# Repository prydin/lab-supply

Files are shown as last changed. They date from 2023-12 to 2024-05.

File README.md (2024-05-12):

# Linear 0-30V, 2A lab power supply

3d rendering

## Disclaimer

This supply has been built and tested and does work. However, I am a hobbyist doing this to learn. You are
welcome to follow along, but keep the experimental status in mind and always exercise caution when dealing
with electricity!

## Abstract

This project aims to design a high-performance, high-stability microcontroller-based lab power supply. I am
mostly doing this to learn, but also because I'm tired of cheap switchmode power supplies delivering power
riddled with RF noise.

## Principle of operation

### High voltage section

The high voltage section is very simple and consists of a regular AC inlet with a safety capacitor across it.
There is a 3A fuse in series with the hot lead and a two pole mains switch. The transformer is a 24V/4A unit
with a 12V center tap. Once rectified, the voltage reaches about 36V at my location. Mains ground is connected
to the chassis as well as the ground output terminal.

### Analog secion

32-36V AC enters the circuit at the `AC1` and `AC2` terminals and gets rectified and smoothed into approximately
36-40V DC. This voltage is then pre-regulated down to 32V through `Q3` which is gets its voltage reference the
backwards bias of `D3`. This voltage is used to power the opamps. The `CNT` input is the transformer center tap,
which should be around 15V and is used to create the +12V and +5V voltages.

The `U1D` opamp acts as a voltage regulation amplifier and expects a control voltage between 0-4.096V on its postive input. The feedback loop is tuned
to 7.32x amplification, resulting in an output voltage ranging from 0-30V. The Darlington pair at `Q3` acts
as a emitter follower current amplifier.

Current regulation is based on a high-side current sensing resistor, `R27`. The differential voltage across the
current sense resistor is amplified to a 0-2.5V signal using an INA225 current sense amplifier. This voltage is
then sent to the positivie input of `U1A`. The control circuitry feeds a 0-4.096V signal
to the `V_ISET` input, which is scaled down to 0-2.5V through a resistor network. This voltage is then fed to the
negative input of `U1A`. When the voltage from the current sense amplifier goes above the control voltage on the negative input,
the opamp will source current to Q2, which brings the base on Q3 low until the current is limited to the
set value. `Q3` is needed since we want to keep R24 relatively low to avoid voltage drop at high output currents,
while making sure `U1A` isn't sourcing or sinking too much current. `Q1` acts as a simple switch for turning on
the current limit indicator LED.

### Digital section

The digital section is based on a Adafruit ItsyBitsy 5V, which is essentially an Atmel ATMega 32u4 with some
support circuitry. This was chosen to simplify the design and keep everything as through hole. The digital
section is responsible for feeding the `V_VSET` and `V_ISET` voltages to the the analog section, as well
as measuring and presenting actual voltages and currents.

A key component is the LMZ4040DBZ voltage reference, which provides a stable 4.096V reference used by the
rest of the circuit.

The control voltages are generated by an MPC4922 12-bit DAC and fed directly to the analog section. The user
sets the desired voltage and current using two rotary encoders which can be pushed to switch between a "fine"
and "coarse" mode.

The output voltage of the supply is measured by an MCP3202 ADC through a voltage divider network to bring the
voltage down to 0-4.096V. Further overvoltage protection is offered by the `D12` clamping diode. Current is
measured in a similar way, but since that signal is in the 0-1V range, it is first amplified 4.096x by `U1B`.
This signal is also clamped to the 4.096V reference through `D10`.

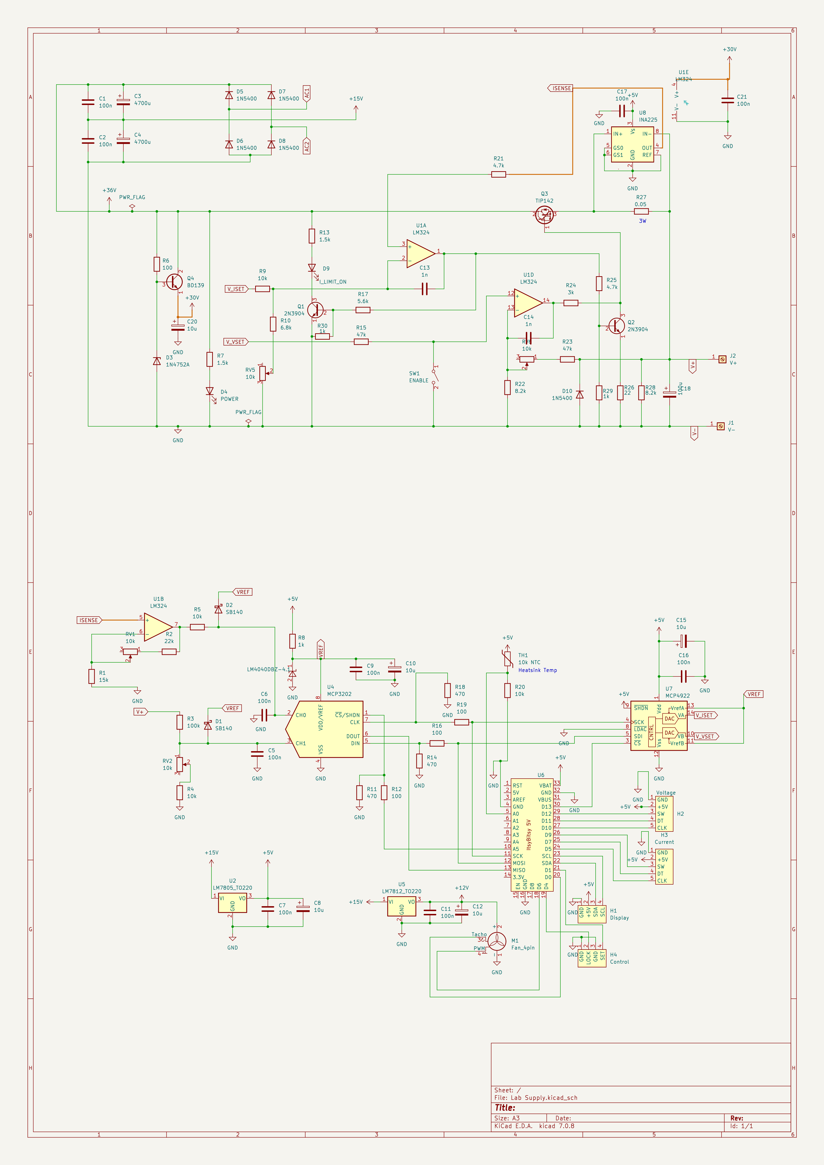
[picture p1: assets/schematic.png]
schematic


## Controls

### Current and voltage

Current and voltage are controlled using two rotary encoders. Pressing the knob switches between coarse and fine
mode. In coarse mode, a blinking cursor will indicate the least significant digit subject to change by turning
the knob.

### Enable/disable

The enable switch enables or disables the output. Notice that this is a "soft" disable that's simply shorting
the posisitive terminal on the voltage regulation opamp to ground. Thus, the output is NOT electrically isolated
from the rest of the circuit.

### Lock mode

When the lock switch is activated, voltage and current output are locked to their current values. The user can
still change the settings, but they are not acted upon. When the switch is flipped, the voltage and current
output is changed to the current setting. This is useful when a user is carefully dialing in new settings
without changing the output while turning the knobs. When locked mode is activated, the "->" symbol between
set and actual values on the display is changed to "LCK".

## Grounding

This power supply is designed to be floating, i.e. it is isolated from ground. If the user needs either
output (plus or minus) to be grounded, they may simply short it to ground using a ground bar or patch
wire. Since the supply uses high side current sense, accidental shorts to ground should not cause damage.

## Physical design and enclosure

### PCB design

This is my very first PCB design and there are many beginners mistakes present in the design. However, it
does work. If I ever redesign this, I would make the +36V path shorter, for example. There are also some
questionable component placements. As with any open source project, you are encouraged to improve on it!
internals

### Enclosure

I opted for a cheap sheet metal/plastic box that is widely available on sites like Ali Express and Amazon.
It works well, but the metal is fairly thin and tends to flex when unplugging the leads.
enclosure

### Cooling

The TIP142 output transistor requires good cooling. I opted for a simple $9 AMD CPU cooler and bolted the
transistor and the 7805 regulator to it. I'm currently using isolating pads for the TIP142, but I'm not
entirely happy with the heat transfer. I might remove that, although I'm not sure I like to have unregulated 36V
exposed inside the case. The fan is PWM controlled using a simple temperature curve algorithm.
cooling

### Rotary encoders and switches

The rotary encoders and switches (with exception of the mains switch) are all cheap Amazon products and work
well so far.

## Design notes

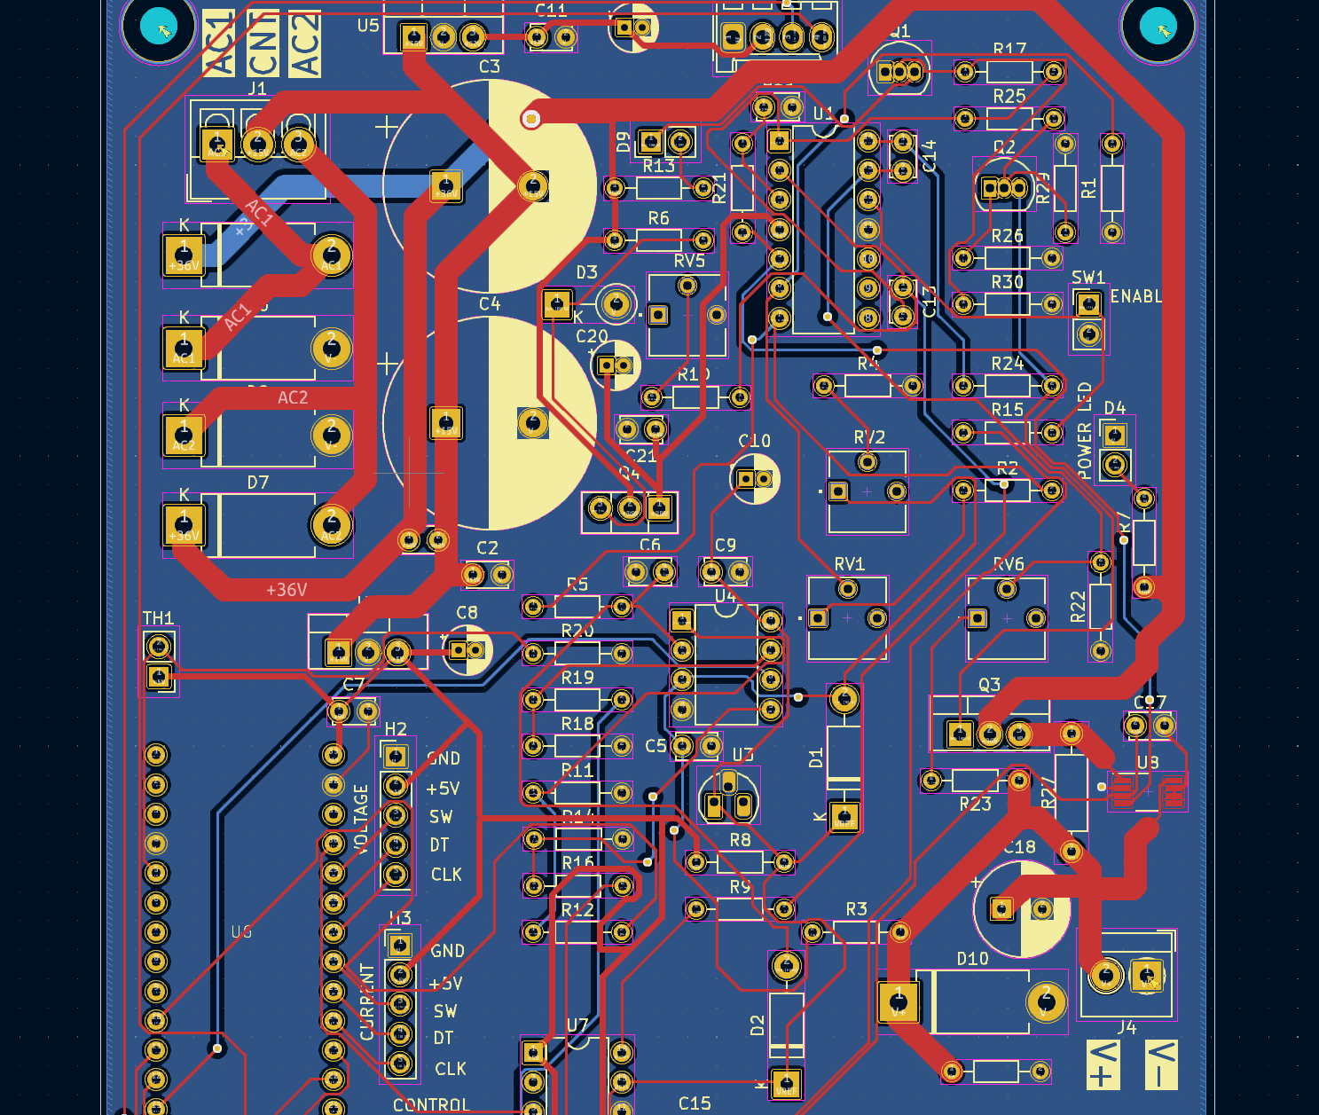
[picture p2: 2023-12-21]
assets/3dmodel.png

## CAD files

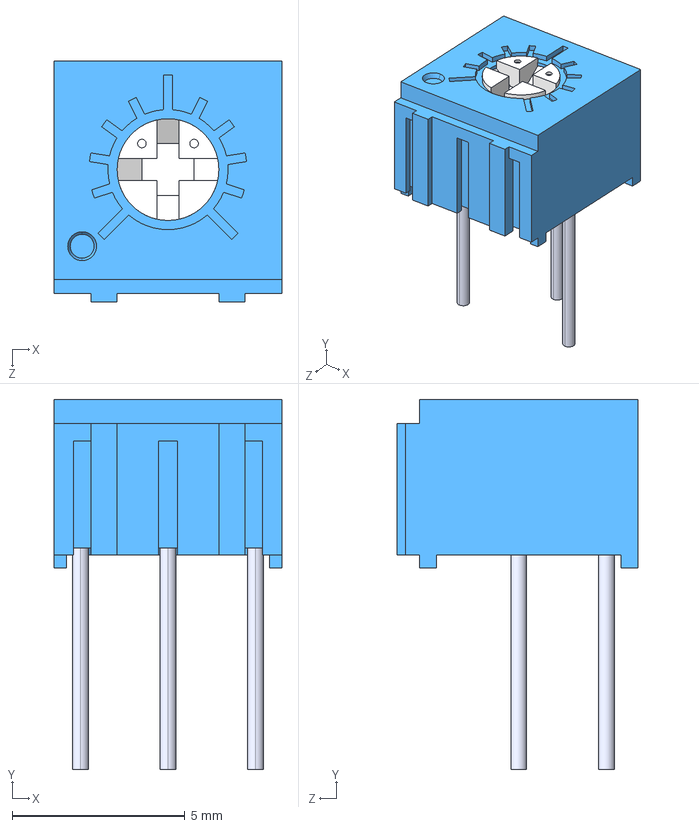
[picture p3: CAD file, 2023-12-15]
3362P-1-253LF.step
6.60 x 10.7 x 6.99 mm

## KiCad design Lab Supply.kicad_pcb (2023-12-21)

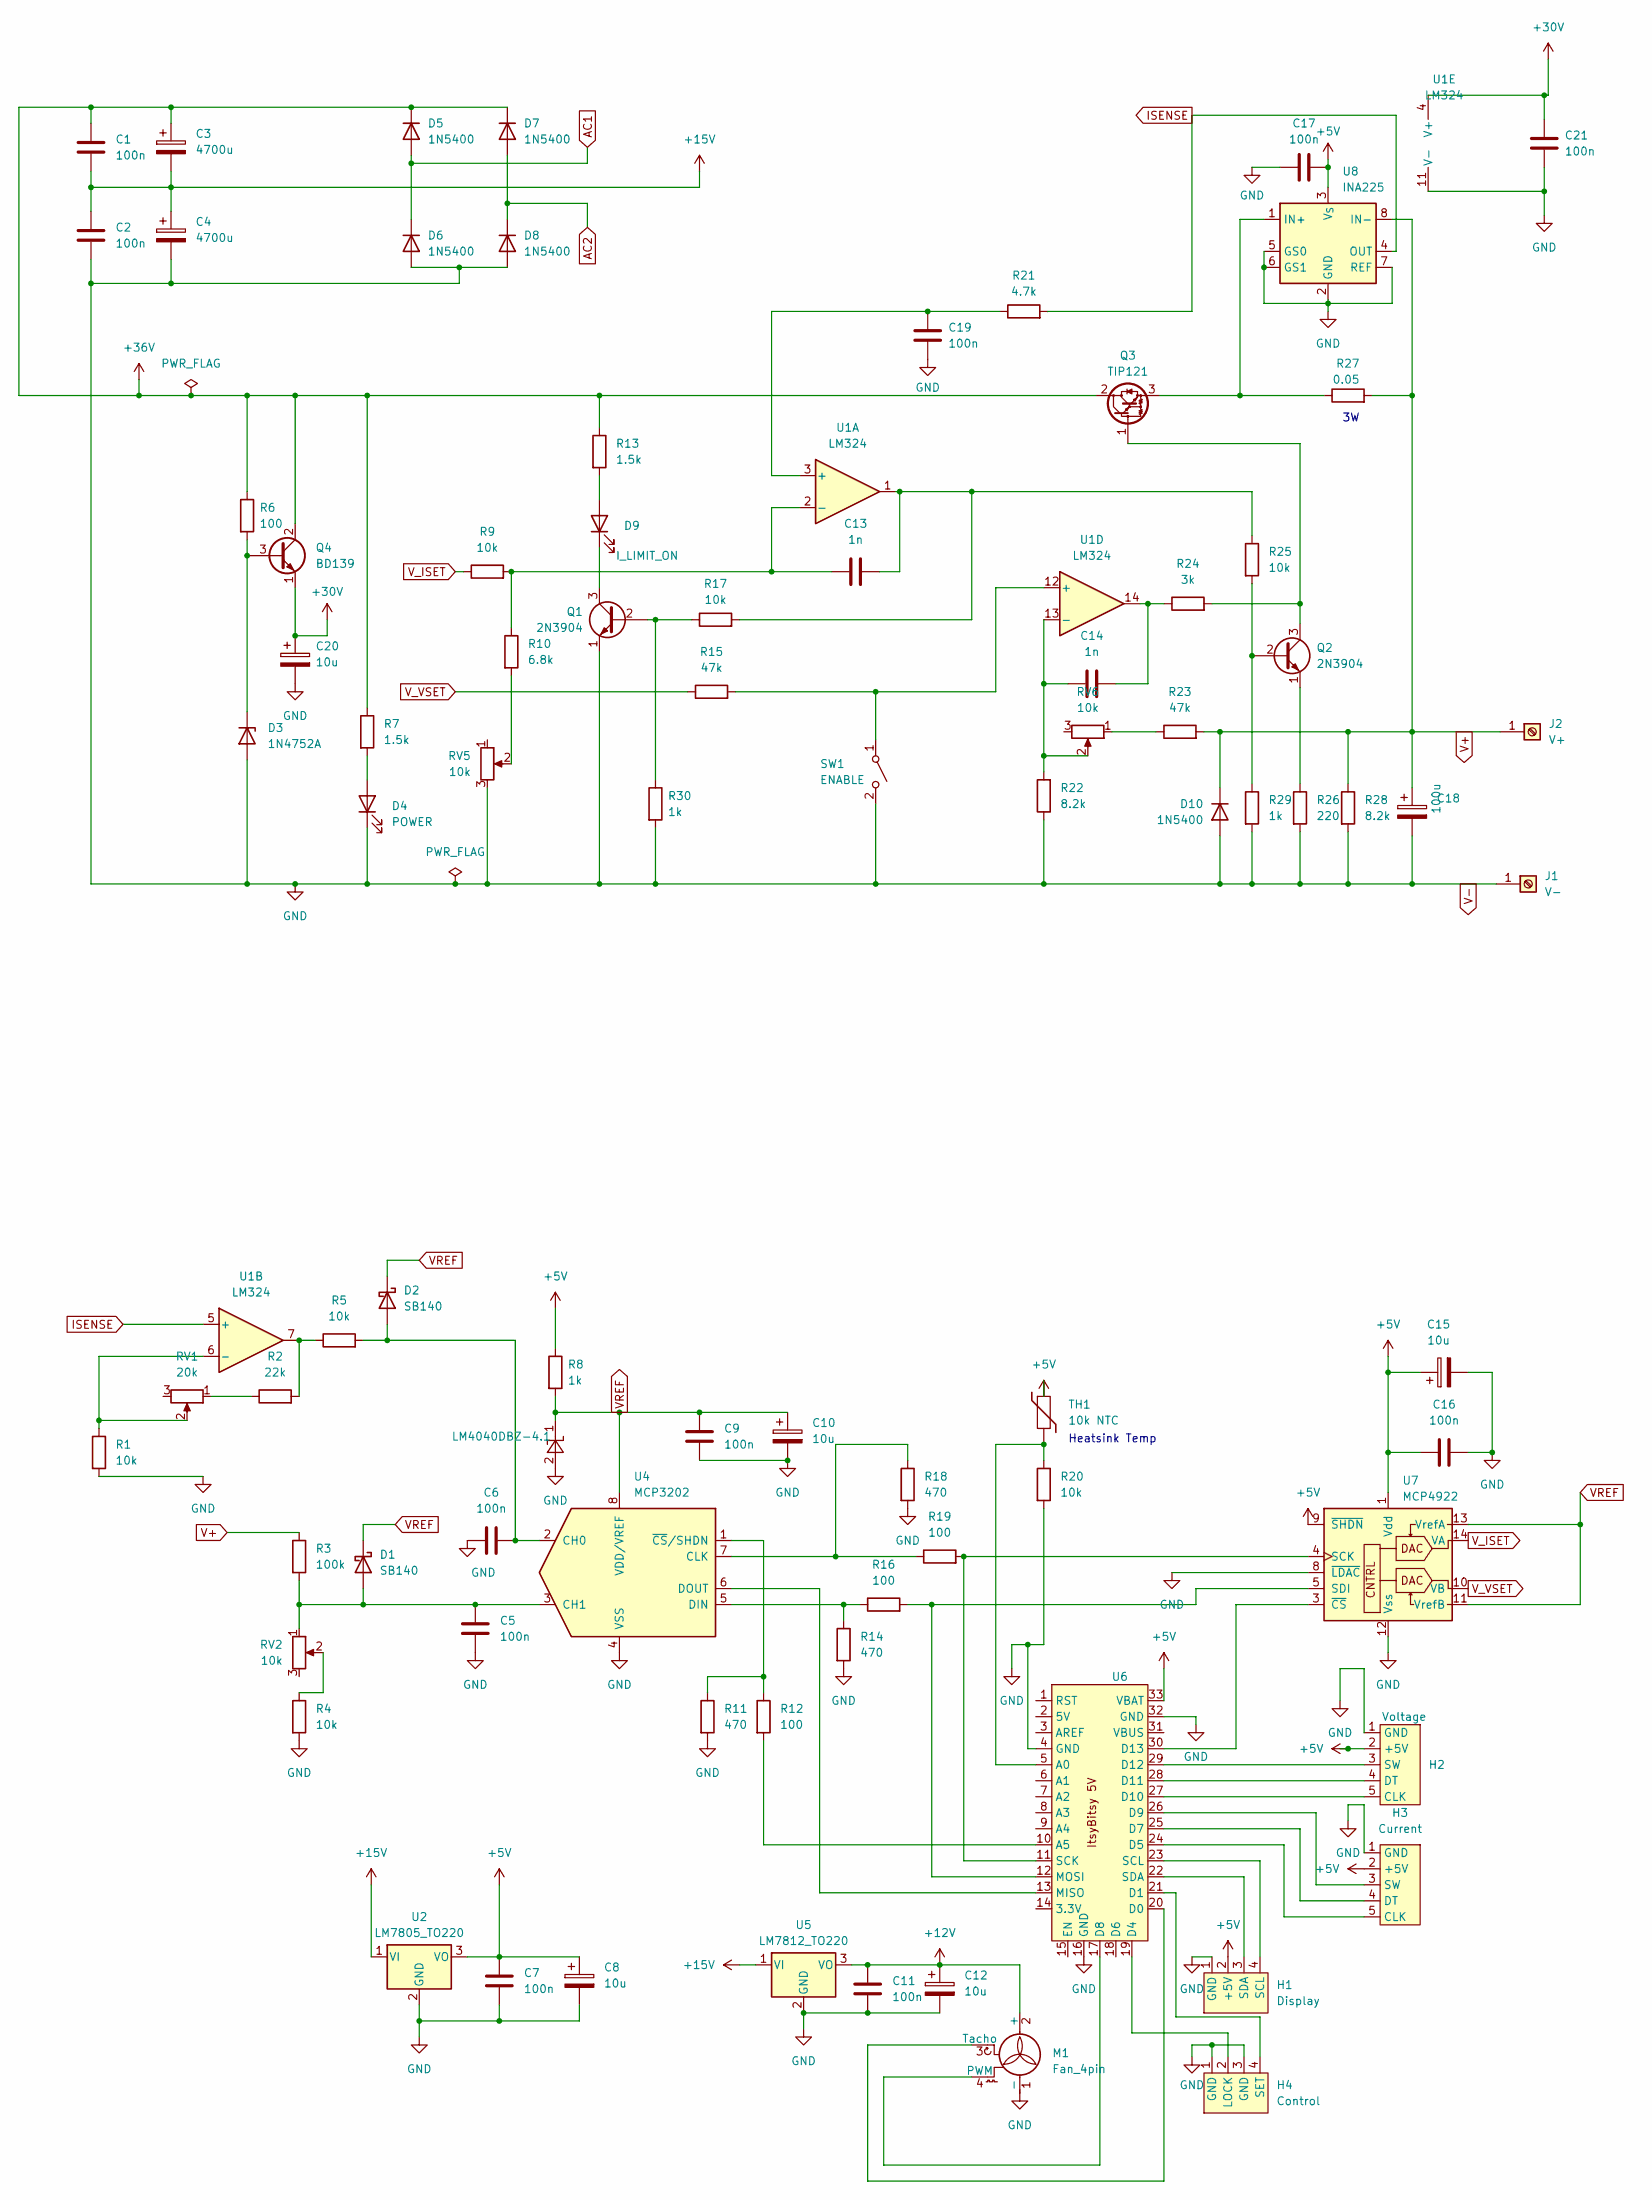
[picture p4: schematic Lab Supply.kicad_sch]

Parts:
C1, C2, C5, C6, C7, C9, C11, C16, C17, C19, C21: 100n; C_Disc_D3.4mm_W2.1mm_P2.50mm
C3, C4: 4700u; CP_Radial_D18.0mm_P7.50mm
C8, C10, C12, C15, C20: 10u; CP_Radial_D4.0mm_P1.50mm
C13, C14: 1n; C_Disc_D3.4mm_W2.1mm_P2.50mm
C18: 100u; CP_Radial_D8.0mm_P3.50mm
D1, D2: SB140; D_DO-41_SOD81_P10.16mm_Horizontal
D3: 1N4752A; D_DO-41_SOD81_P5.08mm_Vertical_KathodeUp
D4: POWER; PinHeader_1x02_P2.54mm_Vertical
D5, D6, D7, D8, D10: 1N5400; D_DO-201AD_P12.70mm_Horizontal
D9: I_LIMIT_ON; PinHeader_1x02_P2.54mm_Vertical
H1: Display; PinHeader_1x04_P2.54mm_Vertical
H2: Voltage; PinHeader_1x05_P2.54mm_Vertical
H3: Current; PinHeader_1x05_P2.54mm_Vertical
H4: Control; PinHeader_1x04_P2.54mm_Vertical
J1: V-
J2: V+
M1: Fan_4pin; Molex_KK-254_AE-6410-04A_1x04_P2.54mm_Vertical
Q1, Q2: 2N3904; TO-92_Inline
Q3: TIP121; TO-220-3_Vertical
Q4: BD139; TO-126-3_Vertical
R1, R4, R5, R9, R17, R20, R25: 10k; R_Axial_DIN0204_L3.6mm_D1.6mm_P7.62mm_Horizontal
R2: 22k; R_Axial_DIN0204_L3.6mm_D1.6mm_P7.62mm_Horizontal
R3: 100k; R_Axial_DIN0204_L3.6mm_D1.6mm_P7.62mm_Horizontal
R6, R12, R16, R19: 100; R_Axial_DIN0204_L3.6mm_D1.6mm_P7.62mm_Horizontal
R7, R13: 1.5k; R_Axial_DIN0204_L3.6mm_D1.6mm_P7.62mm_Horizontal
R8, R29, R30: 1k; R_Axial_DIN0204_L3.6mm_D1.6mm_P7.62mm_Horizontal
R10: 6.8k; R_Axial_DIN0204_L3.6mm_D1.6mm_P7.62mm_Horizontal
R11, R14, R18: 470; R_Axial_DIN0204_L3.6mm_D1.6mm_P7.62mm_Horizontal
R15, R23: 47k; R_Axial_DIN0204_L3.6mm_D1.6mm_P7.62mm_Horizontal
R21: 4.7k; R_Axial_DIN0204_L3.6mm_D1.6mm_P7.62mm_Horizontal
R22, R28: 8.2k; R_Axial_DIN0204_L3.6mm_D1.6mm_P7.62mm_Horizontal
R24: 3k; R_Axial_DIN0204_L3.6mm_D1.6mm_P7.62mm_Horizontal
R26: 220; R_Axial_DIN0204_L3.6mm_D1.6mm_P7.62mm_Horizontal
R27: 0.05; R_Axial_DIN0207_L6.3mm_D2.5mm_P10.16mm_Horizontal
RV1: 20k; TRIM_3362P-1-253LF
RV2, RV5, RV6: 10k; TRIM_3362P-1-253LF
SW1: ENABLE; PinHeader_1x02_P2.54mm_Vertical
TH1: 10k NTC; PinHeader_1x02_P2.54mm_Vertical
U1: LM324; DIP-14_W7.62mm
U2: LM7805_TO220; TO-220-3_Vertical
U3: LM4040DBZ-4.1; TO-92_HandSolder
U4: MCP3202; DIP-8_W7.62mm
U5: LM7812_TO220; TO-220-3_Vertical
U6: Itsy Bitsy 5V
U7: MCP4922; DIP-14_W7.62mm
U8: INA225; VSSOP-8_3.0x3.0mm_P0.65mm

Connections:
+5V: C7.1, C8.1, C15.1, C16.1, C17.2, H1.2 (+5V), H2.2 (+5V), H3.2 (+5V), R8.1, TH1.1, U2.3 (VO), U6.33 (VBAT), U7.1 (Vdd), U7.9 (~SHDN), U8.3 (V_{S})
+12V: C11.1, C12.1, M1.2 (+), U5.3 (VO)
+15V: C1.2, C2.1, C3.2, C4.1, J1.2, U2.1 (VI), U5.1 (VI)
+28V: C20.1, C21.1, Q4.1 (E), U1.4 (V+)
+36V: C1.1, C3.1, D5.1 (K), D7.1 (K), Q3.2 (C), Q4.2 (C), R6.1, R7.1, R13.1
AC2: D7.2 (A), D8.1 (K), J1.3
ISENSE: R21.2, U1.5 (+), U8.4 (OUT)
unnamed: C13.2, R17.2, R25.1, U1.1
unnamed: C14.1, R24.1, U1.14
unnamed: C5.1, D1.2 (A), R3.2, RV2.1, U4.3 (CH1)
unnamed: C6.2, D2.2 (A), R5.2, U4.2 (CH0)
unnamed: D3.1 (K), Q4.3 (B), R6.2
unnamed: D4.2 (A), R7.2
unnamed: D9.2 (A), R13.2
unnamed: D9.1 (K), Q1.3 (C)
unnamed: H1.4 (SCL), U6.23 (SCL)
unnamed: H1.3 (SDA), U6.22 (SDA)
unnamed: H2.5 (CLK), U6.27 (D10)
unnamed: H2.4 (DT), U6.28 (D11)
unnamed: H2.3 (SW), U6.29 (D12)
unnamed: H3.5 (CLK), U6.24 (D5)
unnamed: H3.4 (DT), U6.25 (D7)
unnamed: H3.3 (SW), U6.26 (D9)
unnamed: H4.2 (LOCK), U6.19 (D4)
unnamed: H4.4 (SET), U6.21 (D1)
unnamed: M1.4 (PWM), U6.17 (D8)
unnamed: M1.3 (Tacho), U6.20 (D0)
unnamed: Q1.2 (B), R17.1, R30.1
unnamed: Q2.2 (B), R25.2, R29.1
unnamed: Q2.3 (C), Q3.1 (B), R24.2
unnamed: Q2.1 (E), R26.1
unnamed: Q3.3 (E), R27.1, U8.1 (IN+)
unnamed: R2.1, RV1.1
unnamed: R2.2, R5.1, U1.7
unnamed: R4.1, RV2.2
unnamed: R10.2, RV5.2
unnamed: R23.1, RV6.1
unnamed: R15.2, SW1.1 (A), U1.12 (+)
unnamed: C19.1, R21.1, U1.3 (+)
unnamed: C13.1, R9.2, R10.1, U1.2 (-)
unnamed: R1.1, RV1.2, U1.6 (-)
unnamed: C14.2, R22.2, RV6.2, U1.13 (-)
unnamed: R18.1, R19.1, U4.7 (CLK)
unnamed: R14.1, R16.1, U4.5 (DIN)
unnamed: U4.6 (DOUT), U6.13 (MISO)
unnamed: R11.1, R12.1, U4.1 (~CS/SHDN)
unnamed: R20.1, TH1.2, U6.5 (A0)
unnamed: R12.2, U6.10 (A5)
unnamed: U6.30 (D13), U7.3 (~CS)
unnamed: R16.2, U6.12 (MOSI), U7.5 (SDI)
unnamed: R19.2, U6.11 (SCK), U7.4 (SCK)
V+: C18.1, D10.1 (K), J2.1, R3.1, R23.2, R27.2, R28.1, U8.8 (IN-); also elsewhere on the board
VREF: C9.1, C10.1, D1.1 (K), D2.1 (K), R8.2, U3.1 (K), U4.8 (VDD/VREF), U7.11 (VrefB), U7.13 (VrefA)
V_ISET: R9.1, U7.14 (VA)
V_VSET: R15.1, U7.10 (VB)

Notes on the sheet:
Heatsink Temp

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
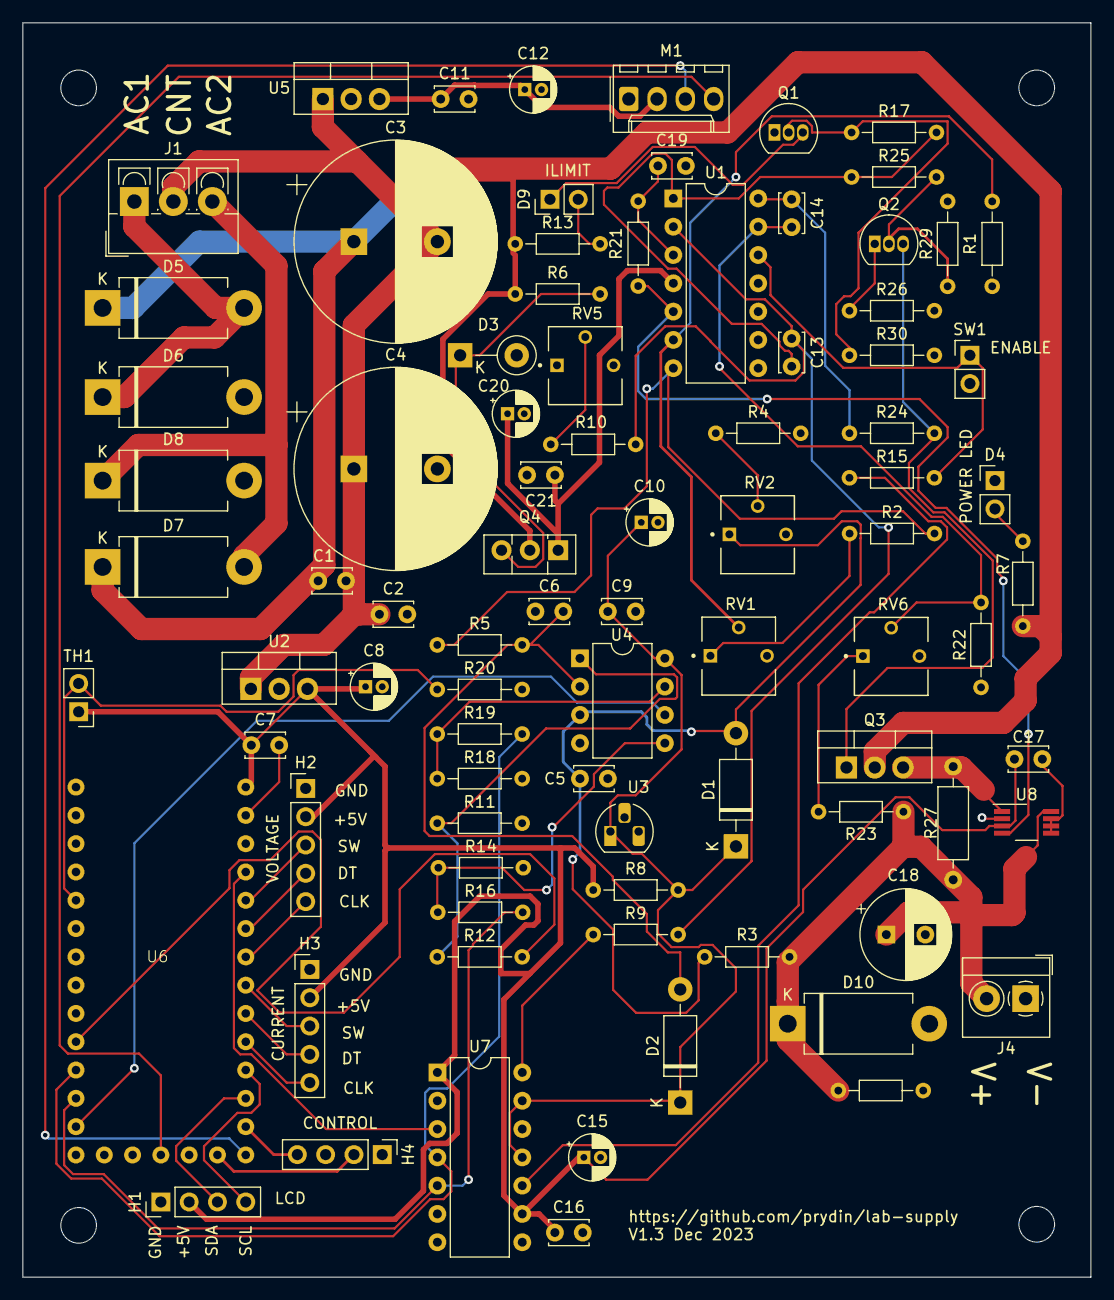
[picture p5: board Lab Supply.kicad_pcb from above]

Board: 2 copper layers, 95.9 x 112.6 mm, 86 parts (0 on the bottom side), 57 nets.

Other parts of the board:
J4: OUTPUT; TerminalBlock_4Ucon_1x02_P3.50mm_Horizontal

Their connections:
V+: J4.2; also elsewhere on the board

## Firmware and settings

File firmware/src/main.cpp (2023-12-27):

/*
Copyright 2023, Pontus Rydin

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
THE SOFTWARE IS PROVIDED “AS IS”, WITHOUT WARRANTY OF ANY KIND,
EXPRESS OR IMPLIED, INCLUDING BUT NOT LIMITED TO THE WARRANTIES
OF MERCHANTABILITY, FITNESS FOR A PARTICULAR PURPOSE AND
NONINFRINGEMENT. IN NO EVENT SHALL THE AUTHORS OR COPYRIGHT
HOLDERS BE LIABLE FOR ANY CLAIM, DAMAGES OR OTHER LIABILITY,
WHETHER IN AN ACTION OF CONTRACT, TORT OR OTHERWISE, ARISING
FROM, OUT OF OR IN CONNECTION WITH THE SOFTWARE OR THE USE OR
OTHER DEALINGS IN THE SOFTWARE.
*/
#include <SPI.h>
#include <MCP3202.h>
#define USE_TIMER_3 true
#include <TimerInterrupt.h>
#include <ISR_Timer.h>
#include <MCP_DAC.h>
#include <RotaryEncoder.h>
#include "Display.hpp"
#include "TempControl.hpp"
#include "Average.hpp"
#include "ControlKnob.hpp"
#include "Calibration.hpp"

// Voltage dial pins
#define ROTARY_DT_1 11
#define ROTARY_CLK_1 10
#define ROTARY_SW_1 12

// Current dial pins
#define ROTARY_DT_2 22 // Fix for broken D7 on my Arduino.
#define ROTARY_CLK_2 5
#define ROTARY_SW_2 9

// ADC/DAC pins
#define DAC_CS 13 // DAC chip select
#define ADC_CS 23 // ADC chip select

// ADC constants
#define ADC_VREF 4096      // ADC reference voltage in millivolts
#define ADC_MAX_VALUE 4096 // Maximum value returned from ADC (2^bits)
#define ADC_CURRENT 0      // Curremt channel
#define ADC_VOLTAGE 1      // Voltage channel

// DAC constants
#define DAC_VOLTAGE 1 // Voltage channel
#define DAC_CURRENT 0 // Current channel

// Timer interrupt
#define ADC_AVG_INT 1000                           // ADC averaging interval (ms)
#define ADC_SAMPLE_INT 100                         // ADC sampling interval (ms)
#define MAX_SAMPLES (ADC_AVG_INT / ADC_SAMPLE_INT) // Number of samples to collect

// Conversion factors and functions (all values in millivolts and milliamps)
#define MAX_MV 30000                                                  // Maximum millivolts the supply can output
#define MAX_MA 2000                                                   // Maximum milliamps the supply can output
#define ADC_TO_RAW_VOLT(x) ((x * ADC_VREF) / ADC_MAX_VALUE)           // Convert ADC reading to actual volts seen on pin
#define ADC_TO_VOLT(x) (ADC_TO_RAW_VOLT(x) * (MAX_MV / ADC_VREF))     // Convert ADC reading to volts on supply output
#define ADC_TO_AMP(x) (MAX_MA * (ADC_TO_RAW_VOLT(x) / ADC_MAX_VALUE)) // Convert ADC reading to amps through load

// Rotary encoder constants
#define MV_PER_CLICK 10
#define MA_PER_CLICK 10

// Fan control constants
#define FAN_PWM_PIN 8          // Fan PWM control pin
#define FAN_SENSOR_PIN 0       // Fan tacho pin
#define THERM_PIN A0           // Thermistor sense pin
#define R_THERM_GROUND 10000.0 // Voltage divider resistance to ground
#define FAN_ON 30.0            // Temp where fan is turned on
#define FAN_MAX 35.0           // Temp where fan is maxed out

// Steinhart-Hart coefficients for Vishay NTCALUG03A103GC
#define THERM_R25 10000.0
#define THERM_COEFF_A 1.145241779e-3
#define THERM_COEFF_B 2.314660102e-4
#define THERM_COEFF_C 0.9841582652e-7

// Overtemp protection
#define OVERTEMP_LIMIT_ON 90  // Overtemp protection turns on
#define OVERTEMP_LIMIT_OFF 80 // Overtemp protection turns off

// Settings lock
#define LOCK_PIN 1 // Settings lock

// Display
Display display;

// Rotary encoders
RotaryEncoder currentEncoder(ROTARY_DT_2, ROTARY_CLK_2, RotaryEncoder::LatchMode::TWO03);
RotaryEncoder voltageEncoder(ROTARY_DT_1, ROTARY_CLK_1, RotaryEncoder::LatchMode::TWO03);
ControlKnob currentDial(currentEncoder, display, Display::ID::current, 0, MAX_MA, 10, 100, ROTARY_SW_2);
ControlKnob voltageDial(voltageEncoder, display, Display::ID::voltage, 0, MAX_MV, 10, 1000, ROTARY_SW_1);

// ADC
MCP3202 adc(ADC_CS);

// DAC
MCP4922 dac;

// Fan
TempControl tempControl(FAN_PWM_PIN, FAN_SENSOR_PIN, FAN_ON, FAN_MAX);

// Averaged readings
Average measVolt(MAX_SAMPLES);
Average measAmp(MAX_SAMPLES);
Average measTemp(MAX_SAMPLES);

// Voltage and current set on dials (millivolts and milliamps)
uint32_t vSet = 0.0;
uint32_t iSet = 0.0;

// Overtemp protection
bool overTemp = false;

// Settings lock
bool locked = false;

float getTemp()
{
  int v = analogRead(THERM_PIN);
  float r2 = (R_THERM_GROUND * (1023.0 / (float)v - 1.0));
  float logR2 = log(r2);
  return (1.0 / (THERM_COEFF_A + THERM_COEFF_B * logR2 + THERM_COEFF_C * logR2 * logR2 * logR2)) - 273.15;
}

void onReadADC()
{
  SPI.beginTransaction(SPISettings(500000, MSBFIRST, SPI_MODE0));
  measVolt.update(ADC_TO_VOLT((float)adc.readChannel(ADC_VOLTAGE)));
  measAmp.update(ADC_TO_AMP((float)adc.readChannel(ADC_CURRENT)));
  measTemp.update(getTemp());
}

void setup()
{
  pinMode(DAC_CS, OUTPUT);
  pinMode(ADC_CS, OUTPUT);
  pinMode(FAN_SENSOR_PIN, INPUT_PULLUP);
  pinMode(FAN_PWM_PIN, OUTPUT);
  pinMode(LOCK_PIN, INPUT_PULLUP);
  digitalWrite(DAC_CS, HIGH);
  digitalWrite(ADC_CS, HIGH);
  Serial.begin(115200);
  SPI.begin();

  // Connect current and voltage dial so coarse mode behaves nicely
  currentDial.setPeer(&voltageDial);
  voltageDial.setPeer(&currentDial);

  // Start timer interrupt
  ITimer3.init();
  ITimer3.attachInterruptInterval(ADC_SAMPLE_INT, onReadADC);

  // Set all DAC output voltages to zero
  dac.begin(DAC_CS);
  dac.analogWrite(0, DAC_CURRENT);
  dac.analogWrite(0, DAC_VOLTAGE);
  display.init();

  // Initialize cooling system
  tempControl.begin();
}

void loop()
{
  // Settings lock enabled?
  bool releaseLock = false;
  if (digitalRead(LOCK_PIN) == 0)
  {
    if (!locked)
    {
      display.setLockedMode(true);
      locked = true;
    }
  }
  else
  {
    if (locked)
    {
      display.setLockedMode(false);
      locked = false;
      releaseLock = true;
    }
  }

  // Overtemp? Disble all dials and keep voltage and current at 0.
  if (!overTemp)
  {
    // Read the dials
    currentDial.tick();
    voltageDial.tick();

    int32_t i = currentDial.getValue();
    int32_t v = voltageDial.getValue();

    // Dials moved?
    if (i != iSet || v != vSet || releaseLock)
    {
      vSet = v;
      iSet = i;

      // Set voltage and current
      if (!locked)
      {
        dac.analogWrite(((uint32_t)dac.maxValue() * toCalibratedVOutput(vSet)) / MAX_MV, DAC_VOLTAGE);
        dac.analogWrite(((uint32_t)dac.maxValue() * toCalibratedIOutput(iSet)) / MAX_MA, DAC_CURRENT);
      }
    }
  }

  // Handle overtemp if needed
  float temp = measTemp.getAvg();
  if (!overTemp && temp > OVERTEMP_LIMIT_ON)
  {
    overTemp = true;
    vSet = 0.0;
    iSet = 0.0;
    dac.analogWrite(0, DAC_CURRENT);
    dac.analogWrite(0, DAC_VOLTAGE);
    display.overtemp();
  }
  if (overTemp && temp < OVERTEMP_LIMIT_OFF)
  {
    overTemp = false;
    display.normal();
  }

  // Update display (only updates changed values)
  display.setVSet(vSet);
  display.setISet(iSet);
  display.setTemp(round(temp));
  if (!overTemp)
  {
    float amp = measAmp.getAvg(), volt = measVolt.getAvg();

    // We measure in relation to negative supply. Adjust for drop across sense resistor
    float calAmp = toCalibratedIReading(amp);
    float calVolt = toCalibratedVReading(volt);
    display.setVAct(calVolt);
    display.setIAct(calAmp);
    display.setPAct((calAmp * calVolt) / 1000);
  }
  display.setRpm(tempControl.getCachedSpeed());
  display.refresh();

  // Set fan speed
  tempControl.setTemp(temp);
}

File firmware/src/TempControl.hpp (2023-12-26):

/*
Copyright 2023, Pontus Rydin

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
THE SOFTWARE IS PROVIDED “AS IS”, WITHOUT WARRANTY OF ANY KIND,
EXPRESS OR IMPLIED, INCLUDING BUT NOT LIMITED TO THE WARRANTIES
OF MERCHANTABILITY, FITNESS FOR A PARTICULAR PURPOSE AND
NONINFRINGEMENT. IN NO EVENT SHALL THE AUTHORS OR COPYRIGHT
HOLDERS BE LIABLE FOR ANY CLAIM, DAMAGES OR OTHER LIABILITY,
WHETHER IN AN ACTION OF CONTRACT, TORT OR OTHERWISE, ARISING
FROM, OUT OF OR IN CONNECTION WITH THE SOFTWARE OR THE USE OR
OTHER DEALINGS IN THE SOFTWARE.
*/
#include <Arduino.h>
#include <FanController.h>
#include <EEPROM.h>

#define ABORT_THRESHOLD 100000    // Microseconds before we give up looking for a flank
#define SPEED_CHECK_PERIOD 500000 // Microseconds between RPM checks

class TempControl
{
private:
    uint8_t pwmPin;
    uint8_t sensePin;
    float onTemp;
    float maxTemp;
    float slope;
    bool failsafe = false;
    uint16_t cachedSpeed = 0;
    uint32_t lastSpeedReading = 0;

    void setSpeed(uint8_t speed)
    {
        analogWrite(pwmPin, speed);
    }

public:
    TempControl(uint8_t pwmPin, uint8_t sensePin, float onTemp, float maxTemp) : pwmPin(pwmPin), sensePin(sensePin), onTemp(onTemp), maxTemp(maxTemp), slope(255.0 / (maxTemp - onTemp))
    {
    }

    void begin()
    {
    }

    void setTemp(float t)
    {
        // Check for unreiable temp readings
        // TODO: Also check this against current readings. E.g. running at 20C @ 2A wouldn't be realistic.
        if (t < 5)
        {
            failsafe = true;
        }
        if (failsafe || t > maxTemp)
        {
            setSpeed(255);
            return;
        }
        float speed = t > onTemp ? min((t - onTemp) * slope, 255.0) : 0;
        setSpeed(speed);
    }

    uint16_t getCachedSpeed()
    {
        uint32_t now = micros();
        if (now - lastSpeedReading > SPEED_CHECK_PERIOD)
        {
            lastSpeedReading = now;
            cachedSpeed = getSpeed();
        }
        return cachedSpeed;
    }

    uint16_t getSpeed()
    {
        // Simplistic algorithm not using interrupts. Good enough for 5% precision
        // and no risk of disturbing other things requiring interrupts.
        //
        // Wait for a transition. It doesn't matter if it's positive or negative
        uint8_t state = digitalRead(sensePin);
        uint32_t start = micros();
        while (digitalRead(sensePin) == state)
        {
            if (micros() - start > ABORT_THRESHOLD)
            {
                return 0;
            }
        }

        // Find the opposite flank.
        start = micros();
        while (digitalRead(sensePin) != state)
        {
            if (micros() - start > ABORT_THRESHOLD)
            {
                return 0;
            }
        }

        // Finally look for a flank that takes us back to the initial state.
        // We've now completed a perios.
        while (digitalRead(sensePin) == state)
        {
            if (micros() - start > ABORT_THRESHOLD)
            {
                return 0;
            }
        }
        uint32_t now = micros();
        uint32_t period = now - start;
        uint16_t speed = 60.0e6 / (float)period;
        return speed;
    }
};

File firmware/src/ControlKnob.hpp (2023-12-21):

#include <RotaryEncoder.h>
#include "Display.hpp"

class ControlKnob
{
public:
    ControlKnob(RotaryEncoder &knob, Display &display, Display::ID id, int32_t minValue, int32_t maxValue, int16_t slowIncrement, int16_t fastIncrement, int16_t switchPin)
        : knob(knob), display(display), id(id), minValue(minValue), maxValue(maxValue), slowIncrement(slowIncrement), fastIncrement(fastIncrement), switchPin(switchPin)
    {
        pinMode(switchPin, INPUT_PULLUP);
    }

    void tick();

    int32_t getValue()
    {
        return currentValue;
    }

    bool isFast()
    {
        return fast;
    }

    void inline setPeer(ControlKnob *p)
    {
        peer = p;
    }

private:
    ControlKnob *peer;
    RotaryEncoder &knob;
    Display &display;
    int32_t minValue;
    int32_t maxValue;
    int16_t slowIncrement;
    int16_t fastIncrement;
    int16_t switchPin;

    int16_t currentPos = 0;
    bool fast = false;
    bool pressed = false;
    int32_t currentValue = 0;
    Display::ID id;
};

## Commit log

2023-10-22 Changed to LM324
    [Lab Supply.kicad_pcb, Lab Supply.kicad_sch]
2023-10-22 Redesigned CC indicator
    [Lab Supply.kicad_sch]
2023-10-23 Added DA cinverter
    [Lab Supply.kicad_sch]
2023-10-27 Started working on firmware
    [Lab Supply.kicad_pcb, Lab Supply.kicad_sch]
2023-11-01 Rearranged firmware code
    [Lab Supply.kicad_pcb, Lab Supply.kicad_sch]
2023-11-02 Added README
    [Lab Supply.kicad_pcb, Lab Supply.kicad_sch]
2023-11-02 Changed background color of schematic
2023-11-03 Fixed ADC stuff and optimized display updates
    [RotaryEncoder.hpp, main.cpp]
2023-11-03 Corrected reversed display header
    [Lab Supply.kicad_pcb]
2023-11-04 Added fan control
2023-12-15 Added gerber
    [Lab Supply-B_Cu.gbr, Lab Supply-B_Mask.gbr, Lab Supply-B_Paste.gbr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]
2023-12-26 Added voltage calibration
2023-12-26 First working version
    [Lab Supply.kicad_sch]
2023-12-27 Cleaned up documentation. Minor PCB changes
    [Lab Supply-B_Cu.gbr, Lab Supply-B_Mask.gbr, Lab Supply-B_Paste.gbr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]
